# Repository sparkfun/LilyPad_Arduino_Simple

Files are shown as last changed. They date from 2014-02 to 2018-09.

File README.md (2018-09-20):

LilyPad Arduino Simple
======================

LilyPad Arduino Simple Board

[*LilyPad Arduino Simple Board (DEV-10274)*](https://www.sparkfun.com/products/10274)

This LilyPad board is smaller than the LilyPad Main Board, with fewer pins. However, it does have a 
built-in power supply socket, and an on/off switch. 

Repository Contents
-------------------

* **/Hardware** - All Eagle design files (.brd, .sch, .STL)
* **/Production** - Test bed files and production panel files

License Information
-------------------
The hardware is released under [Creative Commons ShareAlike 4.0 International](https://creativecommons.org/licenses/by-sa/4.0/).
The code is beerware; if you see me (or any other SparkFun employee) at the local, and you've found our code helpful, please buy us a round!

Distributed as-is; no warranty is given.

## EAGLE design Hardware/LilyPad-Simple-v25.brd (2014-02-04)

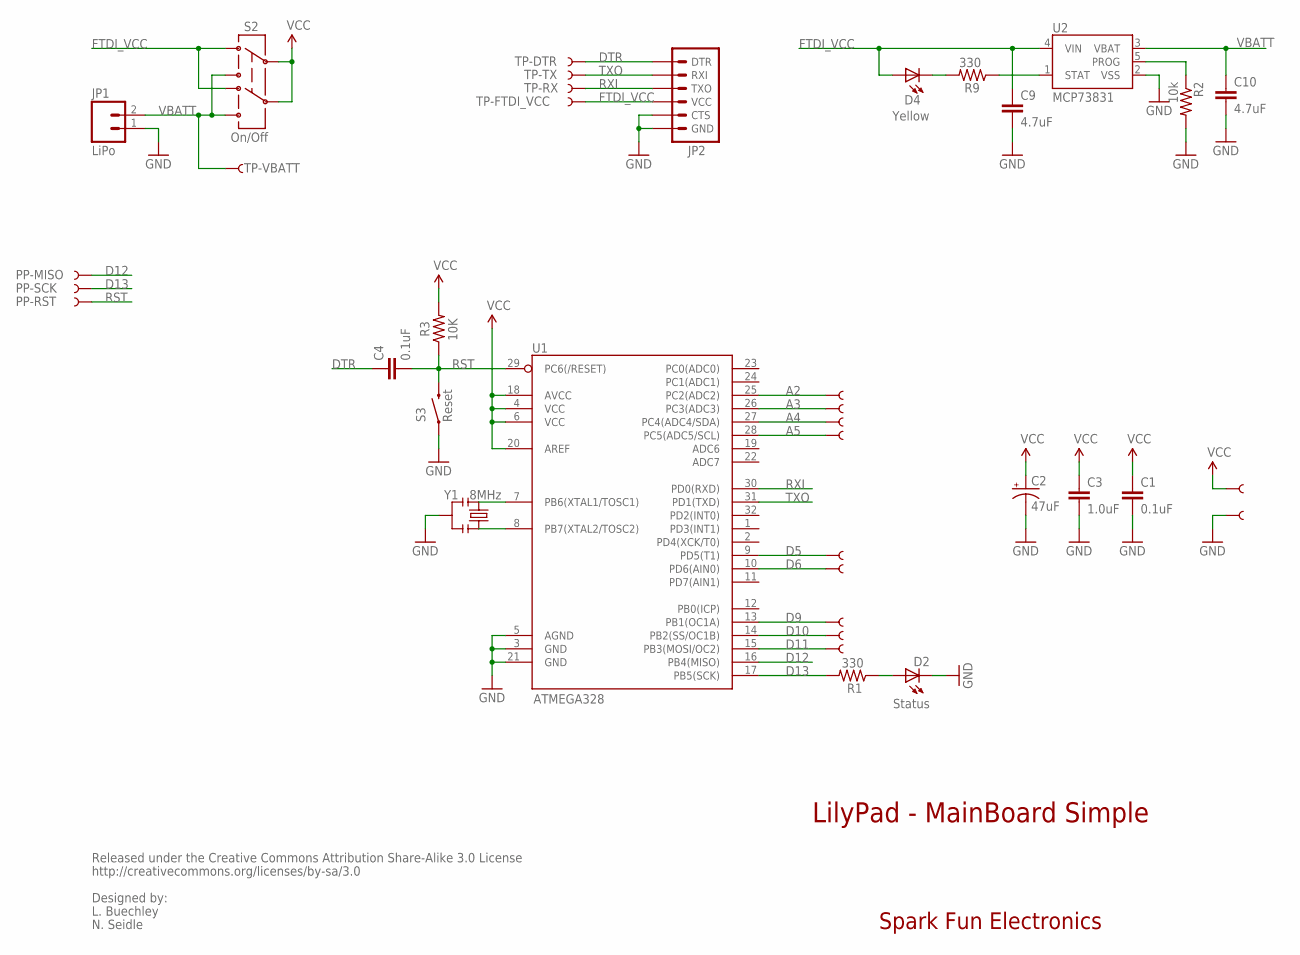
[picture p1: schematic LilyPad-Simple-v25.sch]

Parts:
A2/16, A3/17, A4/18, A5/19: SEWTAP9; PETAL-LONG-1-2SIDE
C1, C4: 0.1uF; 0402-CAP
C2: 47uF; EIA3528
C3: 1.0uF; 0402-CAP
C9, C10: 4.7uF; 0402-CAP
D2: Status; LED-0603
D4: Yellow; LED-0603
JP1: LiPo; JST-2-SMD
JP2: ARDUINO_SERIAL_PROGRAMSMD; 1X06-SMD
PP-MISO: TEST-POINT3X5; PAD.03X.05
PP-RST: TEST-POINT3X5; PAD.03X.05
PP-SCK: TEST-POINT3X5; PAD.03X.05
R1, R9: 330; 0402-RES
R2: 10k; 0402-RES
R3: 10K; 0402-RES
S2: On/Off; AYZ0202
S3: Reset; TACTILE_SWITCH_SMD
TP-DTR: TEST-POINT3X5; PAD.03X.05
TP-FTDI_VCC: TEST-POINT3X5; PAD.03X.05
TP-RX: TEST-POINT3X5; PAD.03X.05
TP-TX: TEST-POINT3X5; PAD.03X.05
TP-VBATT: TEST-POINT3X5; PAD.03X.05
U1: ATMEGA328; TQFP32-08
U2: MCP73831; SOT23-5
U$4, U$35, U$37, U$39, U$41, U$43, U$45: SEWTAP9; PETAL-LONG-1-2SIDE
Y1: 8MHz; RESONATOR-SMD

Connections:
A2: A2/16.1, U1.25 (PC2(ADC2))
A3: A3/17.1, U1.26 (PC3(ADC3))
A4: A4/18.1, U1.27 (PC4(ADC4/SDA))
A5: A5/19.1, U1.28 (PC5(ADC5/SCL))
D5: U1.9 (PD5(T1)), U$41.1
D6: U1.10 (PD6(AIN0)), U$35.1
D9: U1.13 (PB1(OC1A)), U$37.1
D10: U1.14 (PB2(SS/OC1B)), U$39.1
D11: U1.15 (PB3(MOSI/OC2)), U$4.1
D12: PP-MISO.P$1, U1.16 (PB4(MISO))
D13: PP-SCK.P$1, R1.2, U1.17 (PB5(SCK))
DTR: C4.1, JP2.1 (DTR), TP-DTR.P$1
FTDI_VCC: C9.1, D4.A, JP2.4 (VCC), S2.3 (1), S2.6 (4), TP-FTDI_VCC.P$1, U2.4 (VIN)
GND: C1.2, C2.C (-), C3.2, C9.2, C10.2, D2.C, JP1.1, JP2.5 (CTS), JP2.6 (GND), R2.2, S3.1, U1.3 (GND), U1.5 (AGND), U1.21 (GND), U2.2 (VSS), U$43.1, Y1.2
unnamed: U1.7 (PB6(XTAL1/TOSC1)), Y1.1
unnamed: D2.A, R1.1
unnamed: U1.8 (PB7(XTAL2/TOSC2)), Y1.3
unnamed: D4.C, R9.2
PROG: R2.1, U2.5 (PROG)
RST: C4.2, PP-RST.P$1, R3.1, S3.3 (2), U1.29 (PC6(/RESET))
RXI: JP2.3 (TXO), TP-RX.P$1, U1.30 (PD0(RXD))
STAT: R9.1, U2.1 (STAT)
TXO: JP2.2 (RXI), TP-TX.P$1, U1.31 (PD1(TXD))
VBATT: C10.1, JP1.2, S2.1 (3), S2.4 (6), TP-VBATT.P$1, U2.3 (VBAT)
VCC: C1.1, C2.A (+), C3.1, R3.2, S2.2, S2.5, U1.4 (VCC), U1.6 (VCC), U1.18 (AVCC), U1.20 (AREF), U$45.1

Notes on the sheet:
LilyPad - MainBoard Simple
Spark Fun Electronics
Released under the Creative Commons Attribution Share-Alike 3.0 License
http://creativecommons.org/licenses/by-sa/3.0
Designed by:
L. Buechley
N. Seidle

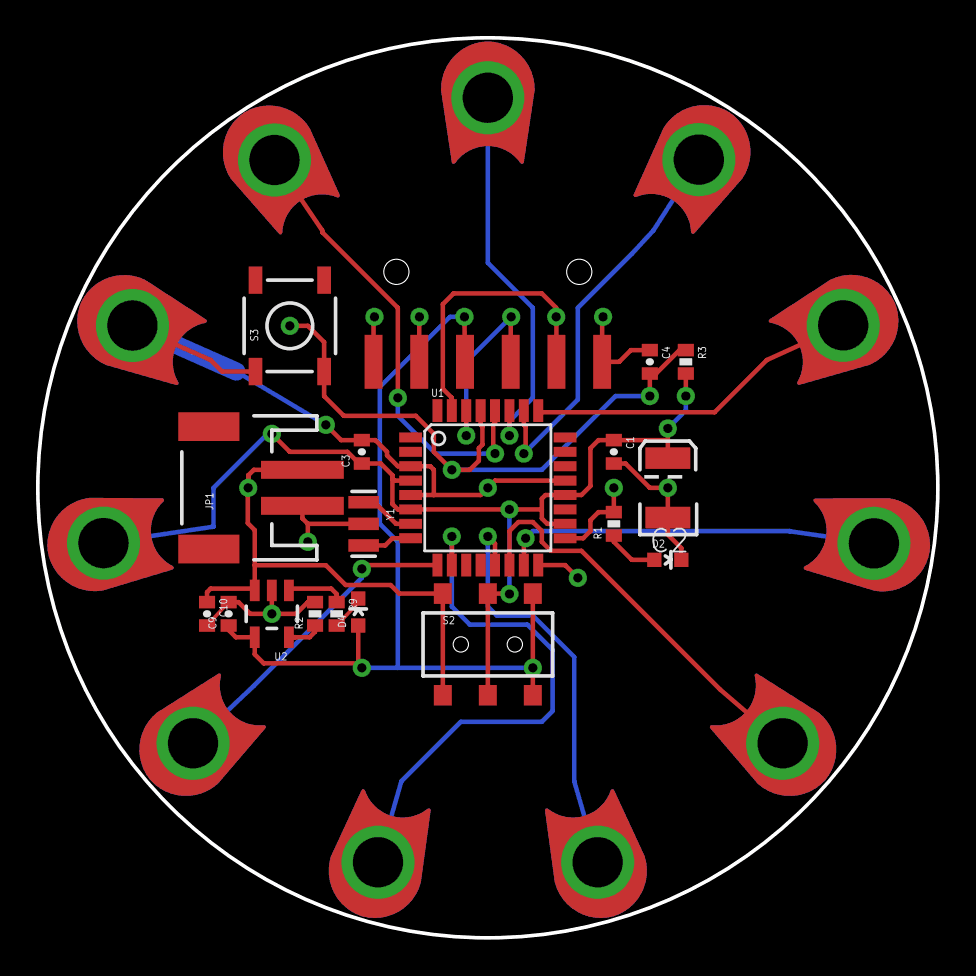
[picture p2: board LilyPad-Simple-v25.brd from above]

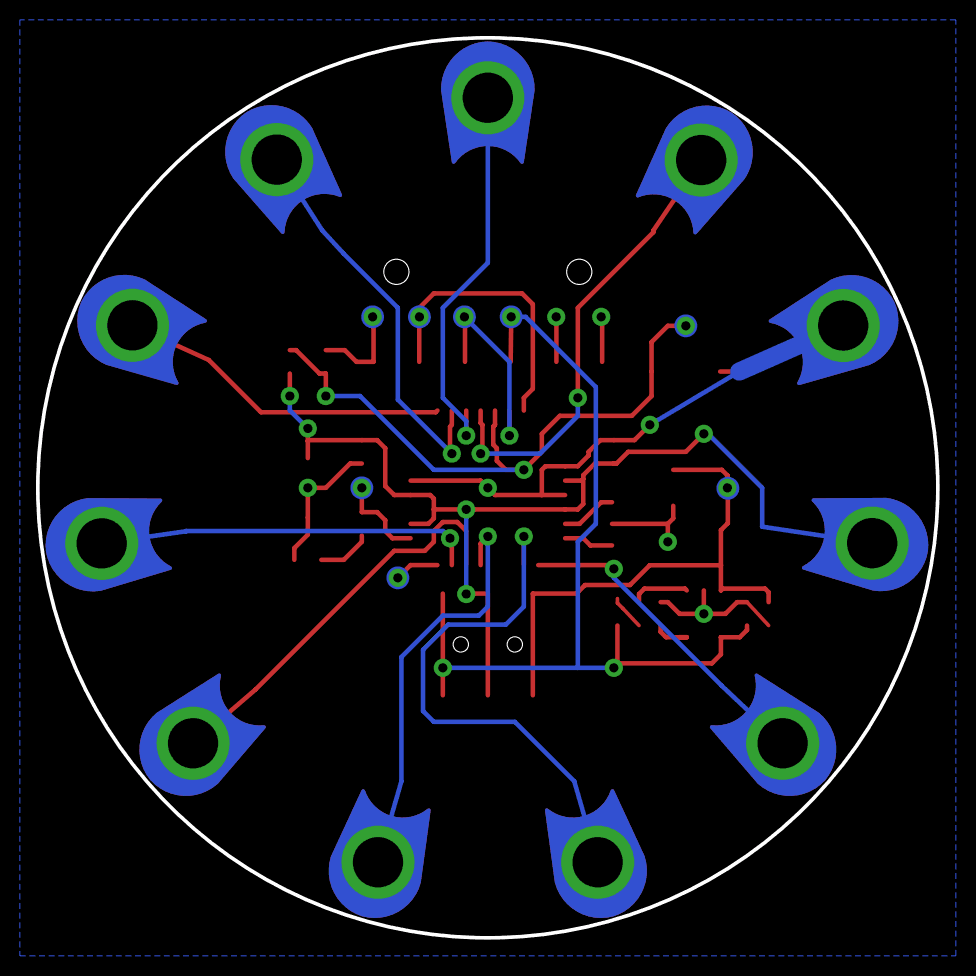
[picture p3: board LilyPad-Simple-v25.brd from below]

Board: 2 copper layers, 50.0 x 50.0 mm, 38 parts (8 on the bottom side), 25 nets.

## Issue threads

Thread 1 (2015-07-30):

Checklist Review for v26 (protos)

lewispg228, 2015-07-30:
1) Is proper attribution given to the original designer? [YES]
comment: the text objects for the designers and revisers and the version # should all be on the symbols layer

2) If net labels are used, are they the correct 'FLAG' type? [NO]
comment: Looks like your RXI and TXO flags (nets) on JP2 have gone missing - perhaps when you deleted test points. please reconnect/reroute

3) Are junction dots used for all 3-wire connections? [YES]
comment: un-necessary node on the 5V net (bottom left of sch)

4) Does every part have a NAME and VALUE (with proper prefix and no '$')? [NO]
comment: ATMEGA328 needs 'U1' and value

5) Is the FTDI connector oriented so the FTDI breakout can be slid on properly (IC side up, header side down)? [NO]
comment: needs nets and traces for TX RX routed/corrected

6) Is the direction of TX/RX serial connections correct? [NO]
comment: can't check yet until they are routed again

7) Does it pass SparkFun DRC? [NO]
comment: 11 errors still present but they are cool to approve

8) Is there a note for a board thickness other than 0.63 inch?  [YES]
comment: should be on tdocu layer

9) Are measurements included for outer dimension and standoffs (Eagle layer 47)? [YES]
comment: the text object "dimension in inches" should also be on layer 47

10) Are all connectors labeled with their purpose? [NO]
comment: "I2C" on both A4 and A5 is helpful, but I think that they should be labeled "SDA" and "CLK" - this is our usual labeling of I2C lines, however I nkow lilypad is never usual

RobotGirlfriend, 2015-08-11:
1) fixed
2) added and re-routed
3) removed
4) un-delete!
5)  I think addressing #2 took care of this as well, if I'm wrong, let me know!
6) Let me know how this looks now
7) Approved
8) Fixed!
9) Moved!
10) Totally agree- in fact, they were labelled that way, and I must have failed to save the change. fixed.

lewispg228, 2015-08-14:
All looks good. thanks!

Closed 2015-08-14.
